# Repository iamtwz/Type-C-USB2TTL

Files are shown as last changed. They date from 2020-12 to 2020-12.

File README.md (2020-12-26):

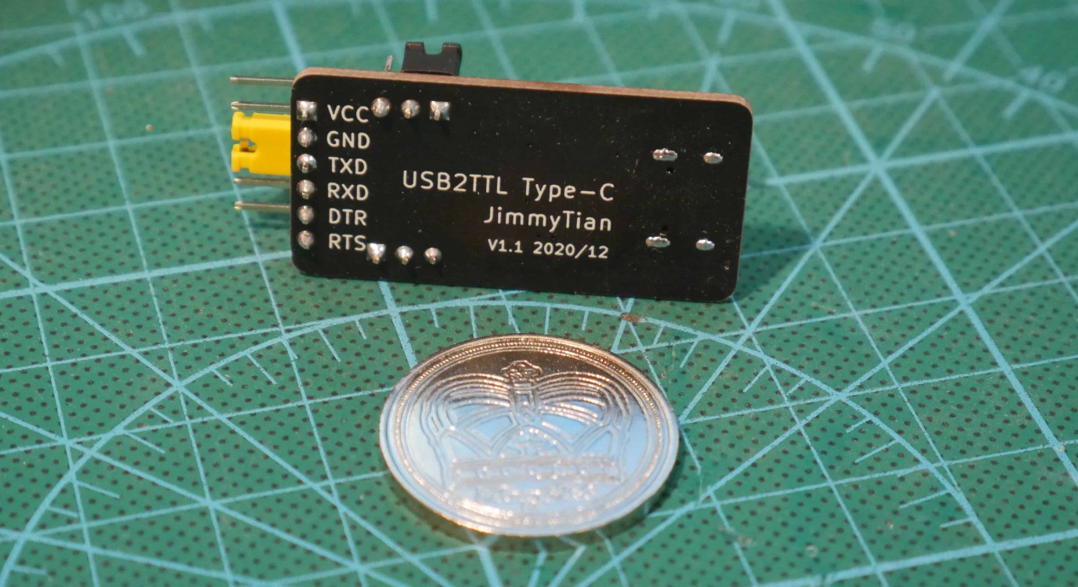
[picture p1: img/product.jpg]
product


一个使用 CH340C 的 USB Type-C 转串口模块

## 功能

- 具有 DTR 引脚，并且可选择是否串联 0.1uF 电容，可实现 Arduino 自动下载
- VCC 电压 5V 与 3V3 可选
- 使用 CH340C，无需外部晶振
- 使用 0805 封装，方便焊接

更多内容：「[做点好玩的：使用 Type-C 的 USB 转串口](https://www.jimmytian.com/archives/a-usb-c-to-ttl-module.html)」

----------

A USB Type-C to TTL Serial Module with CH340C

## Features

- A DTR pin and a optionally 0.1uF capacitor in series, can automatic download Arduino programs.
- VCC 5V and 3V3 selectable
- Using CH340C and no external crystal is required
- Using 0805 package and can be easily soldered

To read more(in Chinese): 「[做点好玩的：使用 Type-C 的 USB 转串口](https://www.jimmytian.com/archives/a-usb-c-to-ttl-module.html)」

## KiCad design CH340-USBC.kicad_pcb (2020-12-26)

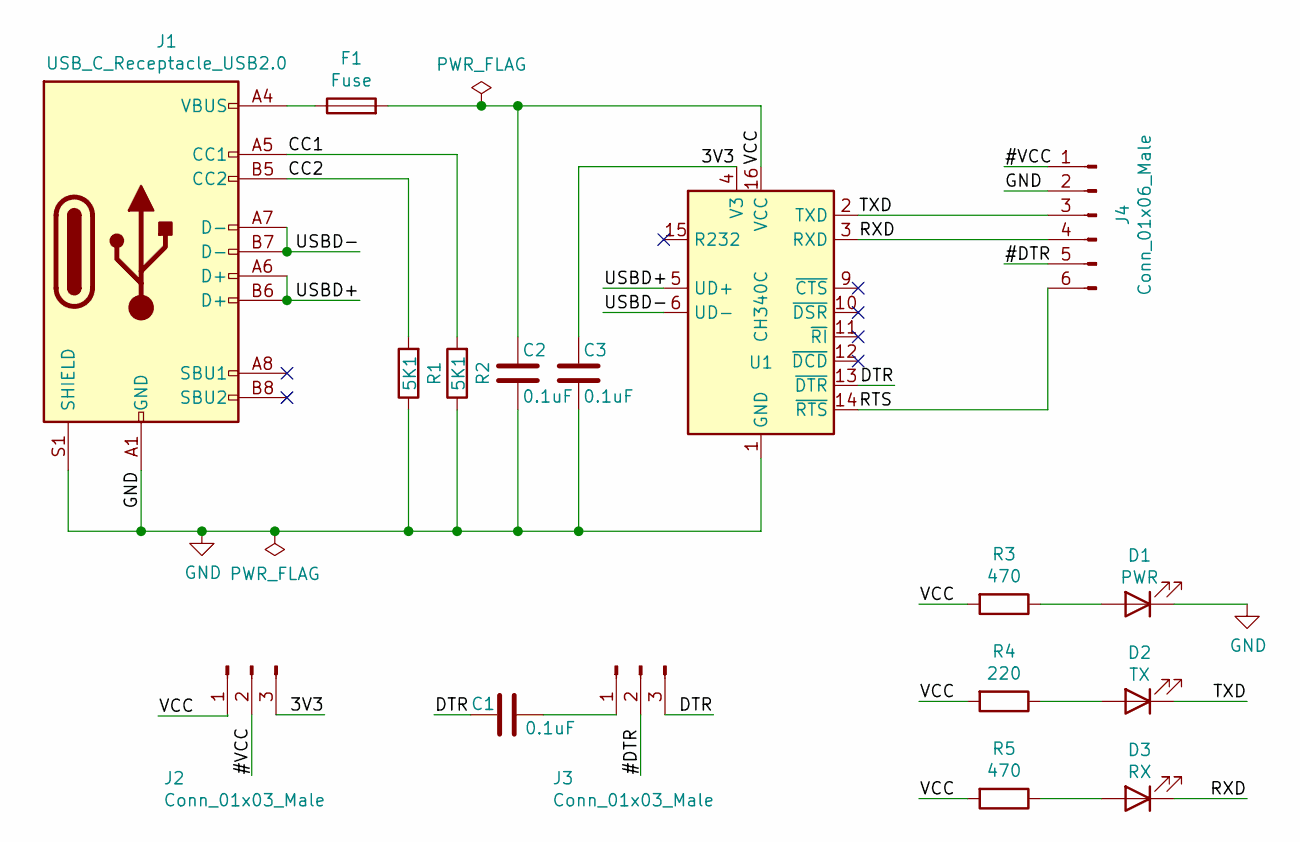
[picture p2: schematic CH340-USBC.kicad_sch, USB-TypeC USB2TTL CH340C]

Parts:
C1, C2, C3: 0.1uF; C_0805_2012Metric
D1: PWR; LED_0805_2012Metric
D2: TX; LED_0805_2012Metric
D3: RX; LED_0805_2012Metric
F1: Fuse; Fuse_0805_2012Metric
J1: USB_C_Receptacle_USB2.0; USB_C_Receptacle_HRO_TYPE-C-31-M-12
J2, J3: Conn_01x03_Male; PinHeader_1x03_P2.54mm_Vertical
J4: Conn_01x06_Male; PinHeader_1x06_P2.54mm_Horizontal
R1, R2: 5K1; R_0805_2012Metric
R3, R5: 470; R_0805_2012Metric
R4: 220; R_0805_2012Metric
U1: CH340C; SOIC-16_3.9x9.9mm_P1.27mm

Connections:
/3V3: C3.1, J2.3, U1.4 (V3)
/#DTR: J3.2, J4.5
/#VCC: J2.2, J4.1
/CC1: J1.A5 (CC1), R2.2
/CC2: J1.B5 (CC2), R1.2
/DTR: C1.1, J3.3, U1.13 (~DTR)
/RTS: J4.6, U1.14 (~RTS)
/RXD: D3.1 (K), J4.4, U1.3 (RXD)
/TXD: D2.1 (K), J4.3, U1.2 (TXD)
/USBD+: J1.A6 (D+), J1.B6 (D+), U1.5 (UD+)
/USBD-: J1.A7 (D-), J1.B7 (D-), U1.6 (UD-)
/VCC: C2.1, F1.2, J2.1, R3.2, R4.2, R5.2, U1.16 (VCC)
GND: C2.2, C3.2, D1.1 (K), J1.A1 (GND), J1.A12 (GND), J1.B1 (GND), J1.B12 (GND), J1.S1 (SHIELD), J4.2, R1.1, R2.1, U1.1 (GND)
unnamed: C1.2, J3.1
unnamed: D1.2 (A), R3.1
unnamed: D2.2 (A), R4.1
unnamed: D3.2 (A), R5.1
unnamed: F1.1, J1.A4 (VBUS), J1.A9 (VBUS), J1.B4 (VBUS), J1.B9 (VBUS)
no_connect_19: J1.A8 (SBU1)
no_connect_20: J1.B8 (SBU2)
no_connect_21: U1.10 (~DSR)
no_connect_22: U1.11 (~RI)
no_connect_23: U1.12 (~DCD)
no_connect_24: U1.15 (R232)
no_connect_25: U1.7 (NC)
no_connect_26: U1.8 (NC)
no_connect_27: U1.9 (~CTS)

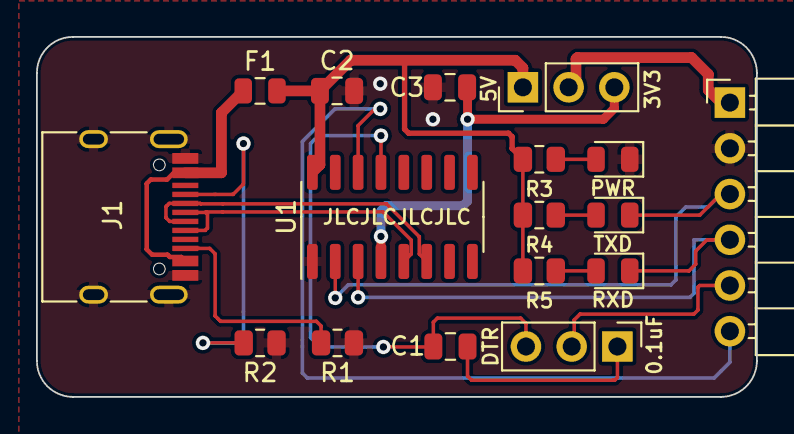
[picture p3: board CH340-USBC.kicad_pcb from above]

Board: 2 copper layers, 40.0 x 20.0 mm, 17 parts (0 on the bottom side), 18 nets.
